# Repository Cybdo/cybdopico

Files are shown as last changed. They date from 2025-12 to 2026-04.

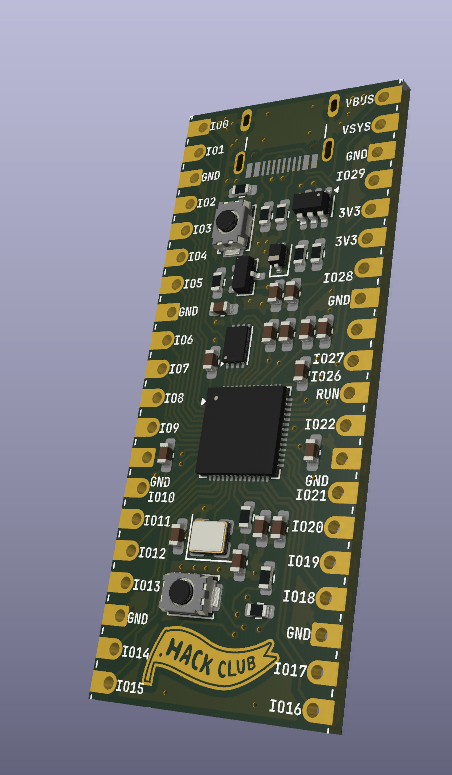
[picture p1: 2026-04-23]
Cover Image.png

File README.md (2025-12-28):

# Cybdo Pico!
RP 2040 based devboard, inspired by the Raspberry Pi Pico and the Orpheus Pico

## Key Features
- RP2040 microcontroller with 16Mibit (2MB) flash
- Raspberry Pi Pico form factor compatiable
- USB-C connectivity
- Dedicated Reset switch
- PCB Touch button (GPIO24)
- All 0603 components where applicable for easier hand soldering
- Pin labels on both sides
- Exposed GPIO29 pin
- Hack Club art :)

## Schematics


## Board




## JLC order


## Firmware
Compatiable with most Pi Pico firmwares, including [MicroPython](https://micropython.org/) and [CircuitPython](https://circuitpython.org/)

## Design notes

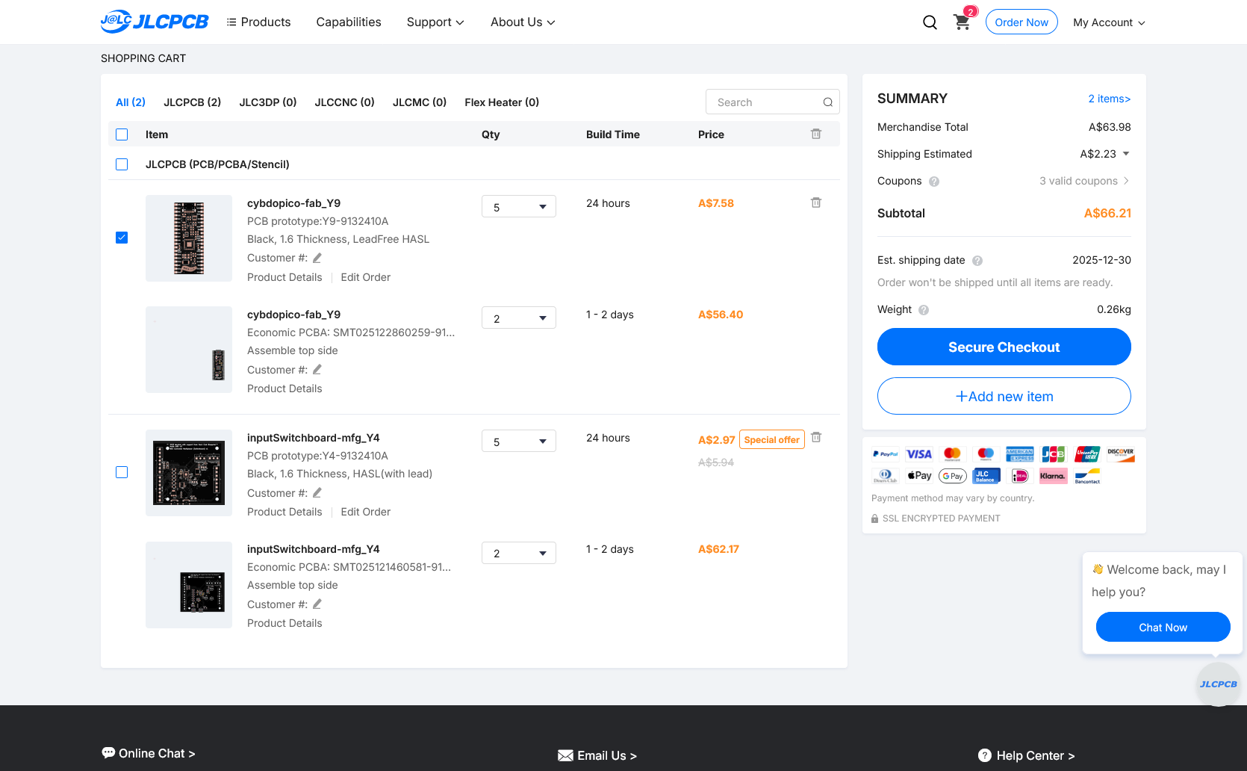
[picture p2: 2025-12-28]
jlcpcb-cart.png

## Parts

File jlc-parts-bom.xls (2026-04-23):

JLCPCB BOM Tool - BOM Matching
BOM name：jlc-parts-bom-JLCPCB Assembly Order.xlsx |  |  | Download Time：2026-01-08 15:04:14 |  |  |  | * Our matching results are updated in real-time, but stock and prices may change. If it's been over 24 hours, please re-match before placing your order.
PCB Assembled Qty：5 |  |  | Est. Total Price：14.3087
Your BOM |  |  |  |  | Matched Parts |  |  |  |  |  |  | Order Information
Top Designator | Bottom Designator | Comment | Footprint | JLCPCB Part # | Matches | Part # | Manufacturer | Footprint | Description | Category | Warning | JLCPCB Part # | Product link | Lib Type | Qty | Source | Total Price ($)
C2,C1 |  | 10uF | C_0603_1608Metric_Pad1.08x0.95mm_HandSolder |  | Select by System | CL10A106KP8NNNC | Samsung Electro-Mechanics | 0603 | 10V 10uF X5R ±10% 0603 Multilayer Ceramic Capacitors MLCC - SMD/SMT ROHS | Multilayer Ceramic Capacitors MLCC - SMD/SMT |  | C19702 | https://jlcpcb.com/partdetail/20411-CL10A106KP8NNNC/C19702 | Basic | 10 | 10 JLCPCB | 0.058
C4,C3 |  | 15pF | C_0603_1608Metric_Pad1.08x0.95mm_HandSolder |  | Select by System | CL10C150JB8NNNC | Samsung Electro-Mechanics | 0603 | 15pF 50V C0G ±5% 0603 Multilayer Ceramic Capacitors MLCC - SMD/SMT ROHS | Multilayer Ceramic Capacitors MLCC - SMD/SMT |  | C1644 | https://jlcpcb.com/partdetail/1996-CL10C150JB8NNNC/C1644 | Basic | 10 | 10 JLCPCB | 0.052
C5,C13 |  | 1uF | C_0603_1608Metric_Pad1.08x0.95mm_HandSolder |  | Select by System | CL10A105KB8NNNC | Samsung Electro-Mechanics | 0603 | 1uF 50V X5R ±10% 0603 Multilayer Ceramic Capacitors MLCC - SMD/SMT ROHS | Multilayer Ceramic Capacitors MLCC - SMD/SMT |  | C15849 | https://jlcpcb.com/partdetail/16531-CL10A105KB8NNNC/C15849 | Basic | 10 | 10 JLCPCB | 0.05
C14,C6,C11,C7,C10,C9,C12,C15,C8 |  | 100nF | C_0603_1608Metric_Pad1.08x0.95mm_HandSolder |  | Select by System | CC0603KRX7R9BB104 | YAGEO | 0603 | 100nF 50V X7R ±10% 0603 Multilayer Ceramic Capacitors MLCC - SMD/SMT ROHS | Multilayer Ceramic Capacitors MLCC - SMD/SMT |  | C14663 | https://jlcpcb.com/partdetail/YAGEO-CC0603KRX7R9BB104/C14663 | Basic | 45 | 45 JLCPCB | 0.1125
D1 |  | 1N5819WS | D_SOD-323 |  | Select by System | 1N5819WS | Guangdong Hottech | SOD-323 | 1A 25A 40V 500uA@40V 600mV@1A SOD-323 Schottky Diodes ROHS | Schottky Diodes |  | C191023 | https://jlcpcb.com/partdetail/GuangdongHottech-1N5819WS/C191023 | Basic | 5 | 5 JLCPCB | 0.0495
P1 |  | USB_C_Plug_USB2.0 | TYPE-C-31-M-12 |  | Select by System | TYPE-C-31-M-12 | Korean Hroparts Elec | SMD | -30℃~+80℃ 1 10,000 cycles 16P 20V 5A 7.35mm Female Surface Mount, Right Angle Type-C SMD USB Connectors ROHS | USB Connectors |  | C165948 | https://jlcpcb.com/partdetail/Korean_HropartsElec-TYPE_C_31_M12/C165948 | Extended | 5 | 5 JLCPCB | 0.8815
R1,R2 |  | 27R | R_0603_1608Metric_Pad0.98x0.95mm_HandSolder |  | Select by System | 0603WAF270JT5E | UNI-ROYAL(Uniroyal Elec) | 0603 | -55℃~+155℃ 100mW 27Ω 75V Thick Film Resistor ±1% ±200ppm/℃ 0603 Chip Resistor - Surface Mount ROHS | Chip Resistor - Surface Mount |  | C25190 | https://jlcpcb.com/partdetail/25933-0603WAF270JT5E/C25190 | Extended | 20 | 20 JLCPCB | 0.024
R4,R3 |  | 5k1R | R_0603_1608Metric_Pad0.98x0.95mm_HandSolder |  | Select by System | 0603WAF5101T5E | UNI-ROYAL(Uniroyal Elec) | 0603 | -55℃~+155℃ 100mW 5.1kΩ 75V Thick Film Resistor ±1% ±100ppm/℃ 0603 Chip Resistor - Surface Mount ROHS | Chip Resistor - Surface Mount |  | C23186 | https://jlcpcb.com/partdetail/23913-0603WAF5101T5E/C23186 | Basic | 10 | 10 JLCPCB | 0.011
R5 |  | 10kR | R_0603_1608_Metric |  | Select by Customer | 0603WAF1002T5E | UNI-ROYAL(Uniroyal Elec) | 0603 | -55℃~+155℃ 100mW 10kΩ 75V Thick Film Resistor ±1% ±100ppm/℃ 0603 Chip Resistor - Surface Mount ROHS | Chip Resistor - Surface Mount |  | C25804 | https://jlcpcb.com/partdetail/26547-0603WAF1002T5E/C25804 | Basic | 5 | 5 JLCPCB | 0.0055
R6,R8,R14 |  | 1kR | R_0603_1608Metric |  | Select by System | 0603WAF1001T5E | UNI-ROYAL(Uniroyal Elec) | 0603 | -55℃~+155℃ 100mW 1kΩ 75V Thick Film Resistor ±1% ±100ppm/℃ 0603 Chip Resistor - Surface Mount ROHS | Chip Resistor - Surface Mount |  | C21190 | https://jlcpcb.com/partdetail/21904-0603WAF1001T5E/C21190 | Basic | 15 | 15 JLCPCB | 0.018
R7 |  | 1MR | R_0603_1608Metric |  | Select by System | 0603WAF1004T5E | UNI-ROYAL(Uniroyal Elec) | 0603 | -55℃~+155℃ 100mW 1MΩ 75V Thick Film Resistor ±1% ±100ppm/℃ 0603 Chip Resistor - Surface Mount ROHS | Chip Resistor - Surface Mount |  | C22935 | https://jlcpcb.com/partdetail/23662-0603WAF1004T5E/C22935 | Basic | 5 | 5 JLCPCB | 0.0055
SW2,SW1 |  | BOOTSEL | SW_Push_SPST_NO_Alps_SKRK |  | Select by System | TS-1088-AR02016 | XUNPU | SMD,4x3mm | -30℃~+80℃ 1.6N 100,000 Cycles 12V 2mm 3mm 4mm 50mA Black Round Button SMD(SMT) Tab SPST Surface Mount,Vertical Without Bracket SMD,4x3mm Tactile Switches ROHS | Tactile Switches |  | C720477 | https://jlcpcb.com/partdetail/XUNPU-TS_1088AR02016/C720477 | Basic | 10 | 10 JLCPCB | 0.442
U1 |  | RP2040 | QFN-56-1EP_7x7mm_P0.4mm_EP3.2x3.2mm |  | Select by System | RP2040 | Raspberry Pi | LQFN-56(7x7) | 12bit 133MHz 30 LQFN-56(7x7) Microcontrollers (MCU/MPU/SOC) ROHS | Microcontrollers (MCU/MPU/SOC) |  | C2040 | https://jlcpcb.com/partdetail/RaspberryPi-RP2040/C2040 | Extended | 5 | 5 JLCPCB | 4.769
U2 |  | USBLC6-2SC6 | SOT-23-6 |  | Select by System | USBLC6-2SC6 | TECH PUBLIC | SOT-23-6 | -55℃~+125℃ 0.35pF 12V 150W 2 5V 6A 6V 80nA ESD IEC 61000-4-2 Unidirectional SOT-23-6 ESD and Surge Protection (TVS/ESD) ROHS | ESD And Surge Protection (TVS/ESD) |  | C2827654 | https://jlcpcb.com/partdetail/TECHPUBLIC-USBLC62SC6/C2827654 | Extended | 9 | 9 JLCPCB | 0.3492
U3 |  | W25Q16JVUXIQ | Winbond_USON-8-1EP_3x2mm_P0.5mm_EP0.2x1.6mm |  | Select by System | W25Q16JVUXIQ | Winbond Elec | USON-8-EP(2x3) | -40℃~+85℃ 100,000 Cycles 10uA 133MHz 16Mbit 2.7V~3.6V 20 Years 3ms SPI USON-8-EP(2x3) NOR FLASH ROHS | NOR FLASH |  | C2843335 | https://jlcpcb.com/partdetail/WinbondElec-W25Q16JVUXIQ/C2843335 | Extended | 5 | 5 JLCPCB | 4.012
U4 |  | MCP1700x-330xxTT | SOT-23 |  | Select by System | MCP1700T-3302E/TT | Microchip Tech | SOT-23 | -40℃~+125℃@(Tj) 1 1.6uA 178mV@(250mA) 250mA 3.3V 44dB@(100Hz) 6V Fixed Over Temperature Protection Positive SOT-23 Voltage Regulators - Linear, Low Drop Out (LDO) Regulators ROHS | Voltage Regulators - Linear, Low Drop Out (LDO) Regulators |  | C39051 | https://jlcpcb.com/partdetail/MicrochipTech-MCP1700T_3302ETT/C39051 | Extended | 5 | 5 JLCPCB | 1.7845
Y1 |  | ABM8-272-T3 | Crystal_SMD_Abracon_ABM8G-4Pin_3.2x2.5mm |  | Select by System | ABM8-272-T3 | Abracon LLC | SMD3225-4P | SMD3225-4P Crystals ROHS | Crystals |  | C20625731 | https://jlcpcb.com/partdetail/AbraconLLC-ABM8_272T3/C20625731 | Extended | 5 | 5 JLCPCB | 1.6845

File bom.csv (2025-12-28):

Item | Cost (AUD) | Cost(USD)
PCB | 7.58 | 5.09
PCBA | 56.40 | 37.84
Shipping | 2.23 | 1.49
Total | 66.21 | 44.42

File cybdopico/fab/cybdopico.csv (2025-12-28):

Id | Designator | Footprint | Quantity | Designation | Supplier and ref
1 | R8,R14 | R_0603_1608Metric | 2 | 1kR
2 | C2,C1 | C_0603_1608Metric_Pad1.08x0.95mm_HandSolder | 2 | 10uF
3 | R4,R3 | R_0603_1608Metric_Pad0.98x0.95mm_HandSolder | 2 | 5k1R
4 | U4 | SOT-23 | 1 | MCP1700x-330xxTT
5 | C4,C3 | C_0603_1608Metric_Pad1.08x0.95mm_HandSolder | 2 | 15pF
6 | U1 | QFN-56-1EP_7x7mm_P0.4mm_EP3.2x3.2mm | 1 | RP2040
7 | C14,C6,C11,C7,C10,C9,C12,C15,C8 | C_0603_1608Metric_Pad1.08x0.95mm_HandSolder | 9 | 100nF
8 | R1,R2 | R_0603_1608Metric_Pad0.98x0.95mm_HandSolder | 2 | 27R
9 | U2 | SOT-23-6 | 1 | USBLC6-2SC6
10 | P1 | TYPE-C-31-M-12 | 1 | USB_C_Plug_USB2.0
11 | R5 | R_0603_1608Metric_Pad0.98x0.95mm_HandSolder | 1 | 10kR
12 | U3 | Winbond_USON-8-1EP_3x2mm_P0.5mm_EP0.2x1.6mm | 1 | W25Q16JVUXIQ
13 | SW1 | SW_Push_SPST_NO_Alps_SKRK | 1 | BOOTSEL
14 | SW2 | SW_Push_SPST_NO_Alps_SKRK | 1 | RESET
15 | C5,C13 | C_0603_1608Metric_Pad1.08x0.95mm_HandSolder | 2 | 1uF
16 | R6 | R_0603_1608Metric_Pad0.98x0.95mm_HandSolder | 1 | 1kR
17 | Y1 | Crystal_SMD_Abracon_ABM8G-4Pin_3.2x2.5mm | 1 | ABM8-272-T3
18 | D1 | D_SOD-323 | 1 | 1N5819WS
19 | R7 | R_0603_1608Metric | 1 | 1MR

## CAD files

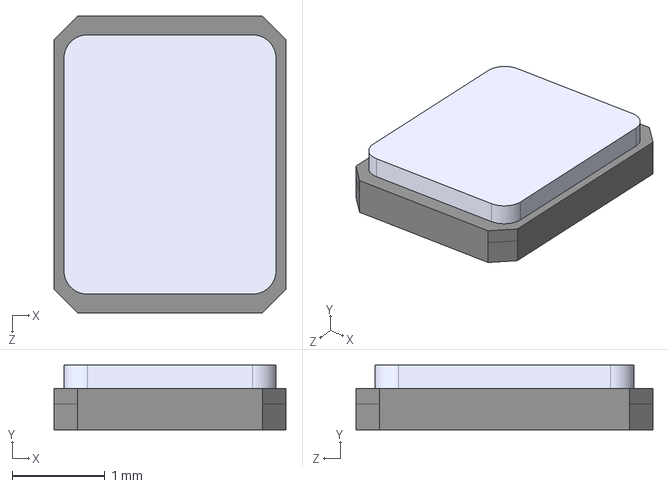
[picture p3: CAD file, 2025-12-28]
cybdopico/imports/ABM8-272-T3.step
2.50 x 0.7 x 3.20 mm

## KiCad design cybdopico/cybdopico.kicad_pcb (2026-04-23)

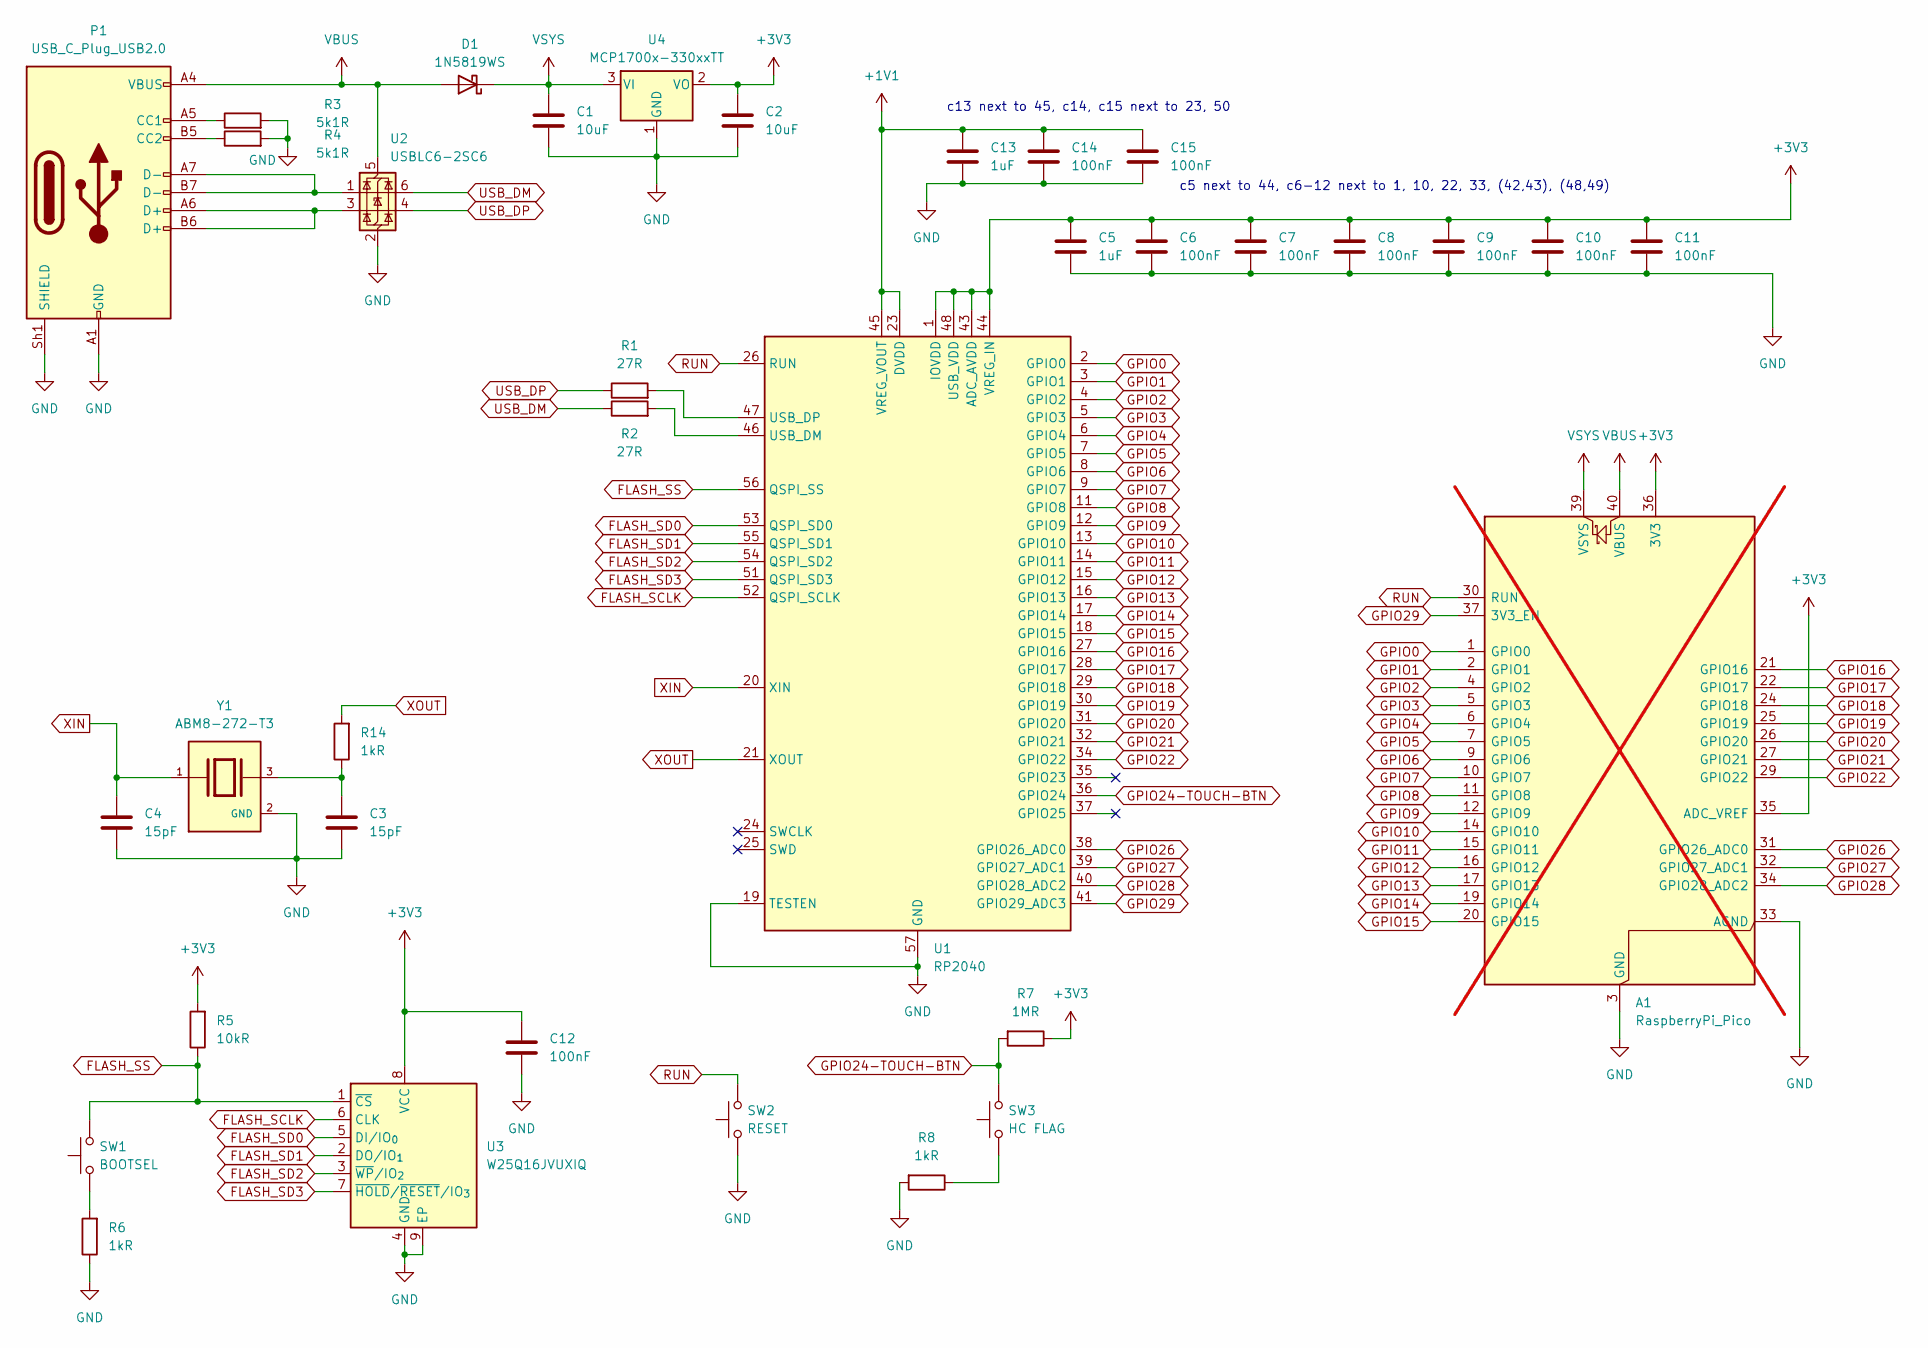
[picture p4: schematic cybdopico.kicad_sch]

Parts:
A1: RaspberryPi_Pico; RaspberryPi_Pico_Common_Unspecified; not fitted
C1, C2: 10uF; C_0603_1608Metric_Pad1.08x0.95mm_HandSolder
C3, C4: 15pF; C_0603_1608Metric_Pad1.08x0.95mm_HandSolder
C5, C13: 1uF; C_0603_1608Metric_Pad1.08x0.95mm_HandSolder
C6, C7, C8, C9, C10, C11, C12, C14, C15: 100nF; C_0603_1608Metric_Pad1.08x0.95mm_HandSolder
D1: 1N5819WS; D_SOD-323
P1: USB_C_Plug_USB2.0; TYPE-C-31-M-12
R1, R2: 27R; R_0603_1608Metric_Pad0.98x0.95mm_HandSolder
R3, R4: 5k1R; R_0603_1608Metric_Pad0.98x0.95mm_HandSolder
R5: 10kR; R_0603_1608Metric_Pad0.98x0.95mm_HandSolder
R6: 1kR; R_0603_1608Metric_Pad0.98x0.95mm_HandSolder
R7: 1MR; R_0603_1608Metric
R8, R14: 1kR; R_0603_1608Metric
SW1: BOOTSEL; SW_Push_SPST_NO_Alps_SKRK
SW2: RESET; SW_Push_SPST_NO_Alps_SKRK
SW3: HC FLAG; hackclub flag touch
U1: RP2040; QFN-56-1EP_7x7mm_P0.4mm_EP3.2x3.2mm
U2: USBLC6-2SC6; SOT-23-6
U3: W25Q16JVUXIQ; Winbond_USON-8-1EP_3x2mm_P0.5mm_EP0.2x1.6mm
U4: MCP1700x-330xxTT; SOT-23
Y1: ABM8-272-T3; Crystal_SMD_Abracon_ABM8G-4Pin_3.2x2.5mm; PARTREV 07-29-20

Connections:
+1V1: C13.1, C14.1, C15.1, U1.23 (DVDD), U1.45 (VREG_VOUT), U1.50 (DVDD)
+3V3: A1.35 (ADC_VREF), A1.36 (3V3), C2.1, C5.1, C6.1, C7.1, C8.1, C9.1, C10.1, C11.1, C12.1, R5.2, R7.1, U1.1 (IOVDD), U1.10 (IOVDD), U1.22 (IOVDD), U1.33 (IOVDD), U1.42 (IOVDD), U1.43 (ADC_AVDD), U1.44 (VREG_IN), U1.48 (USB_VDD), U1.49 (IOVDD), U3.8 (VCC), U4.2 (VO)
FLASH_SCLK: U1.52 (QSPI_SCLK), U3.6 (CLK)
FLASH_SD0: U1.53 (QSPI_SD0), U3.5 (DI/IO_{0})
FLASH_SD1: U1.55 (QSPI_SD1), U3.2 (DO/IO_{1})
FLASH_SD2: U1.54 (QSPI_SD2), U3.3 (~WP/IO_{2})
FLASH_SD3: U1.51 (QSPI_SD3), U3.7 (~HOLD/~RESET/IO_{3})
FLASH_SS: R5.1, SW1.2, U1.56 (QSPI_SS), U3.1 (~CS)
GND: A1.3 (GND), A1.8 (GND), A1.13 (GND), A1.18 (GND), A1.23 (GND), A1.28 (GND), A1.33 (AGND), A1.38 (GND), C1.2, C2.2, C3.2, C4.2, C5.2, C6.2, C7.2, C8.2, C9.2, C10.2, C11.2, C12.2, C13.2, C14.2, C15.2, P1.A1 (GND), P1.A12 (GND), P1.B1 (GND), P1.B12 (GND), P1.Sh1 (SHIELD), R3.2, R4.2, R6.1, R8.2, SW2.1, U1.19 (TESTEN), U1.57 (GND), U2.2 (GND), U3.4 (GND), U3.9 (EP), U4.1 (GND), Y1.2 (GND), Y1.4 (GND)
GPIO0: A1.1 (GPIO0), U1.2 (GPIO0)
GPIO1: A1.2 (GPIO1), U1.3 (GPIO1)
GPIO2: A1.4 (GPIO2), U1.4 (GPIO2)
GPIO3: A1.5 (GPIO3), U1.5 (GPIO3)
GPIO4: A1.6 (GPIO4), U1.6 (GPIO4)
GPIO5: A1.7 (GPIO5), U1.7 (GPIO5)
GPIO6: A1.9 (GPIO6), U1.8 (GPIO6)
GPIO7: A1.10 (GPIO7), U1.9 (GPIO7)
GPIO8: A1.11 (GPIO8), U1.11 (GPIO8)
GPIO9: A1.12 (GPIO9), U1.12 (GPIO9)
GPIO10: A1.14 (GPIO10), U1.13 (GPIO10)
GPIO11: A1.15 (GPIO11), U1.14 (GPIO11)
GPIO12: A1.16 (GPIO12), U1.15 (GPIO12)
GPIO13: A1.17 (GPIO13), U1.16 (GPIO13)
GPIO14: A1.19 (GPIO14), U1.17 (GPIO14)
GPIO15: A1.20 (GPIO15), U1.18 (GPIO15)
GPIO16: A1.21 (GPIO16), U1.27 (GPIO16)
GPIO17: A1.22 (GPIO17), U1.28 (GPIO17)
GPIO18: A1.24 (GPIO18), U1.29 (GPIO18)
GPIO19: A1.25 (GPIO19), U1.30 (GPIO19)
GPIO20: A1.26 (GPIO20), U1.31 (GPIO20)
GPIO21: A1.27 (GPIO21), U1.32 (GPIO21)
GPIO22: A1.29 (GPIO22), U1.34 (GPIO22)
GPIO24-TOUCH-BTN: R7.2, SW3.2, U1.36 (GPIO24)
GPIO26: A1.31 (GPIO26_ADC0), U1.38 (GPIO26_ADC0)
GPIO27: A1.32 (GPIO27_ADC1), U1.39 (GPIO27_ADC1)
GPIO28: A1.34 (GPIO28_ADC2), U1.40 (GPIO28_ADC2)
GPIO29: A1.37 (3V3_EN), U1.41 (GPIO29_ADC3)
unnamed: C3.1, R14.1, Y1.3
unnamed: P1.A5 (CC1), R3.1
unnamed: P1.B5 (CC2), R4.1
unnamed: P1.A6 (D+), P1.B6 (D+), U2.3 (I/O2)
unnamed: P1.A7 (D-), P1.B7 (D-), U2.1 (I/O1)
unnamed: R6.2, SW1.1
unnamed: R8.1, SW3.1
unnamed: R2.2, U1.46 (USB_DM)
unnamed: R1.2, U1.47 (USB_DP)
RUN: A1.30 (RUN), SW2.2, U1.26 (RUN)
USB_DM: R2.1, U2.6 (I/O1)
USB_DP: R1.1, U2.4 (I/O2)
VBUS: A1.40 (VBUS), D1.2 (A), P1.A4 (VBUS), P1.A9 (VBUS), P1.B4 (VBUS), P1.B9 (VBUS), U2.5 (VBUS)
VSYS: A1.39 (VSYS), C1.1, D1.1 (K), U4.3 (VI)
XIN: C4.1, U1.20 (XIN), Y1.1
XOUT: R14.2, U1.21 (XOUT)

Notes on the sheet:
c5 next to 44, c6-12 next to 1, 10, 22, 33, (42,43), (48,49)
c13 next to 45, c14, c15 next to 23, 50

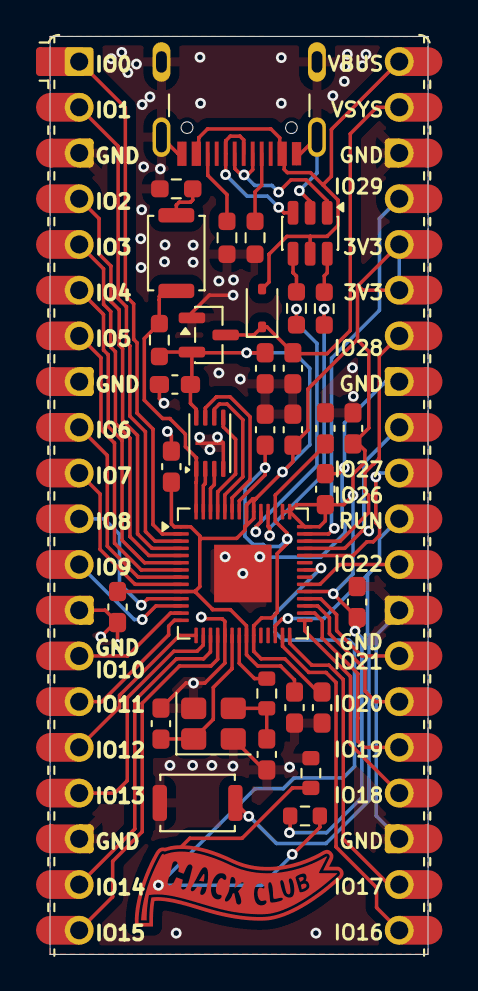
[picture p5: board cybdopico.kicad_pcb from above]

Board: 2 copper layers, 21.0 x 51.0 mm, 35 parts (0 on the bottom side), 53 nets.

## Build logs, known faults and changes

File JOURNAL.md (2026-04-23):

<!--
  This journal is auto generated by Hack Club Blueprint.
-->

# 12/23/2025 - got started with layout  

_Time spent: 0.5h_  

its 11pm but i wanted to get started anyway
im gonna try and speedrun this all tomorrow since i dont really have much time after that.

this is my 3rd time designing a rp2040 minimum system so it should be good...

anyways laid out the footprint and mcu and connected gpio


# 12/24/2025 - locked in and finished rp2040 system  

_Time spent: 4.5h_  

quite a long journal so ill go into depth, i didnt take screenshots along the way tho 

first hour ish: copy rp2040 minimum system from the 2 times that ive done before

I also put it onto the PCB cus im impatient and did stuff out of order, but i'm glad I did because I found that the AMS1117 and my flash module were massive. I took a look at the guide, as well as the schematics for the orpheus pico, and swapped my flash and voltage regulator chip at some point within the first 2 hours

i took a break and dug into how im going to do the touch button. Im inspired by the touch sensitive logo on the bbc microbit and the cool shiny hackclub flag on the orph pico, so I want to turn that into an inbuilt touch button. After a bit of research, i think a resistive solution would be best, by having an outer ring on 3V3 and the inside logo connected to a gpio pin with a big (1M maybe) pulldown resistor to GND. I built the circuit on a breadboard and i'm just waiting on a pico to arrive to test but I'll test this at some point. (30-45 ish mins)

30 ish mins: did some digging into USB protection. found the important things were protecting the data lines with an IC and preventing voltage leaking back into the USB with a diode on VBUS -> VSYS. after looking around myself, i just decided to use the same ones as the orph pico since its tried and tested

45 ish mins: I found that the footprint i was using was for a SMD pico so i went around and deleted the keep out zones for the TPs. I want to make this board as much of a drop in replacement as i can so maybe i'll include it asw but ive never seen anyone use them

then i got back and jumped back and forth between the schematic and pcb procrastinating and trying to lay out the board. plan is probably going to be GPIO traces on the back and most of the other traces on the front but idk.





# 12/26/2025 5 PM - big routing session  

_Time spent: 3.0h_  

routed everything

along the way, i've also has to combine decoupling caps for pins 42 and 43.

also made all my caps 0603 cus i forgot and 0201 has to be standard pcba which is expensive. Also i want to have a crack at handsoldering the 3 non assembled boards I will get so 0603 is best.

Also asked my dad for best practices and help and fixed a few problems i had around that.

I think for my touch button i will do resistive and have 2 pads - one with a 1kR to GND and another connected to a rp2040 pin with a 1MR pull up to 3v3.. theoretically, when a dry finger touches it, worst case assuming 5kR, the rp2040 should be able to sense around 2.2V, which is enough for a digital HIGH. once again, once i get access to hardware, i need to test this.

also decided to scrap the third physical button for now due to space constraints, I'll instead make the LED a WS2812 neopixel (maybe)





# 12/26/2025 10 PM - finishing touches and proofreading  

_Time spent: 1.5h_  

spent a bit proofreading and making sure i didnt make stupid mistakes, luckily i didnt afaik

I went into figma to make a design for the HC flag button - i took the flag from the hc assets page and just added a border. I couldnt figure out proper svg export so I took a screenshot then used illustrator to turn it into a vector (good enough)

then i made a footprint and assigned it to a button I put in the schematics

kicad 9.0.5 which i was running had a bug which caused it to crash if i enabled bypass DRC when routing so i had to update to 9.0.6

I couldnt find any more room for the inbuilt LED so I scrapped that too unfortunately.

when i get home (im out rn) i'll proofread again and test the touch button design

Also i loved the orph pico's GPIO lables so much I recreated it on mine with the jetbrains font. I forgot to mention - I exposed GPIO29(ADC3) since I had no better use for it on the 3v3_EN pin cus I would otherwise leave it NC. The ADC VREF is also just a 3v3.



# 12/28/2025 6 PM - tested touch and finished project  

_Time spent: 0.5h_  

built a circuit using my pico w and 2 resistors, can confirm the touch works even across 2 fingers! now my only concern is the clearance between the 2 pads but according to JLC's DRC it should be ok.
20251228_045600094_iOS

made some gerbers, made a bom and wrote a readme ready to ship!


# 12/28/2025 8 PM - fixed resistorts  

_Time spent: 0.1h_  

just realised i copied the 27R resistors without changing them in like 4 diff places, so i fixed that :heavysob:

no changes to pcba pricing or anything


# 1/4/2026 -  fixed stuff :heavysob:  

_Time spent: 0.1h_  

ive been putting this journal off for a while

aarav alerted me to the fact taht i had 2 unconnected ground planes so i fixed that

also tidied up the routing neat the bottom a bit

ill update github at some point, i have to redo production files and jlc order but it shouldnt change the price or anything



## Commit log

2025-12-23 journal 1
    its 11pm but i wanted to get started anyway
    im gonna try and speedrun this all tomorrow since i dont really have much time after that.
    this is my 3rd time designing a rp2040 minimum system so it should be good...
    anyways laid out the footprint and mcu and connected gpio
    [cybdopico.kicad_sch]
2025-12-28 finished everything
    [ABM8-272-T3.step, bom.csv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]
2025-12-28 update schematic
2025-12-28 fixed resistors and clearned up board (extra vias, traces, etc)
    [cybdopico-B_Cu.gbr, cybdopico-B_Mask.gbr, cybdopico-B_Paste.gbr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]
2026-04-23 made production files
    [cybdopico-B_Cu.gbr, cybdopico-B_Mask.gbr, cybdopico-B_Paste.gbr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]
